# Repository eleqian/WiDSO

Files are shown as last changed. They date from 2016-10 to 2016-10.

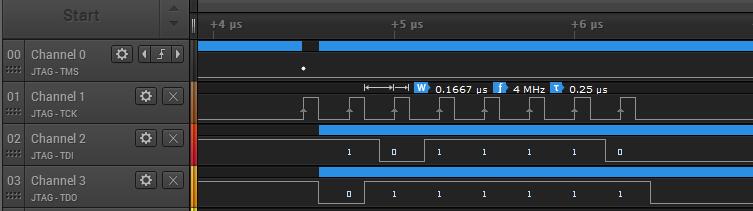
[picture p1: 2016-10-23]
Image/jtag_shift.jpg

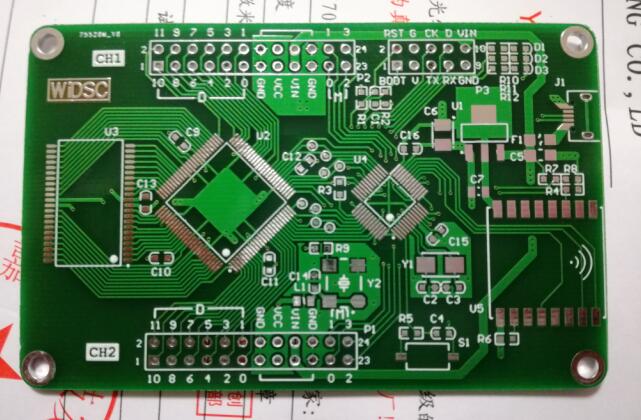
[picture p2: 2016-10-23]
Image/WiDSC_PCB.jpg

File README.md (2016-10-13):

# WiDSO
## 简介
通过Wi-Fi/USB显示和控制的数字示波器（DSO）/逻辑分析仪（LA）/信号发生器（DDS）等。  
由核心板（WiDSC）和扩展板两部分组成，最多可同时搭载两块扩展板。

### 核心板
- 通信接口：Wi-Fi b/g/n，USB FS，UART
- 扩展接口：两路，每路提供12个高速IO和4个ADC/PWM/SPI复用IO
- 存储空间：512k字节@16bits位宽
- 数据速率：采样/输出带宽之和最大100M字节/秒
- 调试方式：内建USB-Blaster和CDC串口，支持U盘方式升级
- 硬件组成：EPM240T100+IS61LV25616+STM32F103C8+ESP8266

### DSO扩展板（计划中）
- 通道数：1CH(8位)
- 采样率：100Mps Max
- 模拟带宽：>20MHz
- 输入幅度：+-4V(x1)/+-40V(x10) Max
- 触发方式：上升沿/下降沿，手动/单次/自动，支持触发信号输入/输出
- 硬件组成：ADC80100/AD9283-100，其余待定

### LA扩展板（计划中）
- 通道数：8CH
- 采样率：100Mps Max
- 输入电平：1.2~5.5V
- 逻辑触发：上升沿/下降沿/电平（任意通道组合），支持和DSO联合触发

### DDS扩展板（计划中）
- 通道数：1CH(8位)
- 采样率：100Mps Max
- 模拟带宽：>20MHz
- 输出幅度：+-4V Max，可调

### TFT扩展板（计划中）
- 分辨率：240*320
- 额外功能：Nor Flash/按键

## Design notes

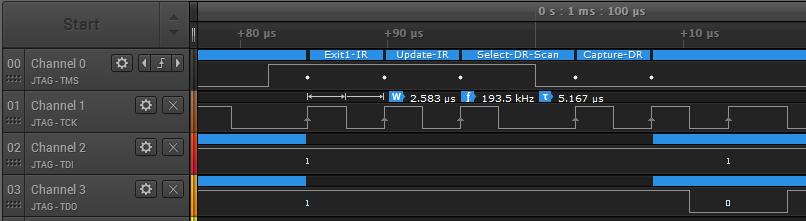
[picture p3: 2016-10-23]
Image/jtag_bitbang.jpg

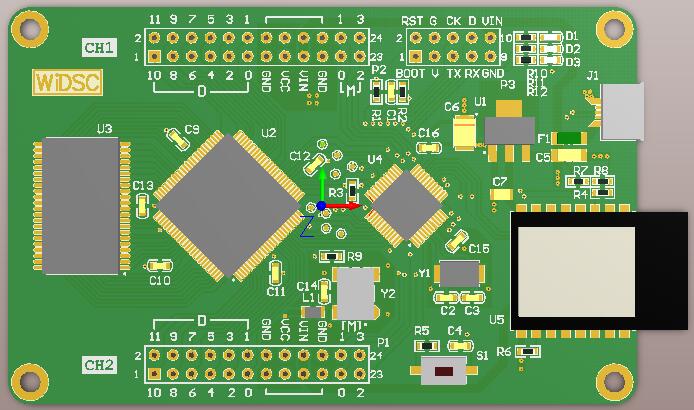
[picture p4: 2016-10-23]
Image/WiDSC_3D.jpg

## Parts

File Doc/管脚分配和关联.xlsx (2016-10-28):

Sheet: SRAM
Pin Designator | Name | Electrical Type
1 | A0 | Input
2 | A1 | Input
3 | A2 | Input
4 | A3 | Input
5 | A4 | Input
6 | C\E\ | Input
7 | IO0 | I/O
8 | IO1 | I/O
9 | IO2 | I/O
10 | IO3 | I/O
11 | VDD | Power
12 | GND | Power
13 | IO4 | I/O
14 | IO5 | I/O
15 | IO6 | I/O
16 | IO7 | I/O
17 | W\E\ | Input
18 | A5 | Input
19 | A6 | Input
20 | A7 | Input
21 | A8 | Input
22 | A9 | Input
23 | A10 | Input
24 | A11 | Input
25 | A12 | Input
26 | A13 | Input
27 | A14 | Input
28 | NC | Passive
29 | IO8 | I/O
30 | IO9 | I/O
31 | IO10 | I/O
32 | IO11 | I/O
33 | VDD | Power
34 | GND | Power
35 | IO12 | I/O
36 | IO13 | I/O
37 | IO14 | I/O
38 | IO15 | I/O
39 | L\B\ | Input
40 | U\B\ | Input
41 | O\E\ | Input
42 | A15 | Input
43 | A16 | Input
44 | A17 | Input

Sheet: MCU
 | ADC | TIM1 | TIM2 | TIM3 | TIM4 | SPI1 | SPI2 | USART1 | USART2 | USART3 | I2C | USB | OTHER
PA0 | * |  | * |  |  |  |  |  | * |  |  |  |  | 扩展接口
PA1 | * |  | * |  |  |  |  |  | * |  |  |  |  | CPLD
PA2 | * |  | * |  |  |  |  |  | * |  |  |  |  | 通信调试
PA3 | * |  | * |  |  |  |  |  | * |  |  |  |  | 其它
PA4 | * |  |  |  |  | *
PA5 | * |  |  |  |  | *
PA6 | * |  |  | * |  | *
PA7 | * | * |  | * |  | *
PA8 |  | *
PA9 |  | * |  |  |  |  |  | *
PA10 |  | * |  |  |  |  |  | *
PA11 |  | * |  |  |  |  |  | * |  |  |  | *
PA12 |  |  |  |  |  |  |  | * |  |  |  | *
PA13 |  |  |  |  |  |  |  |  |  |  |  |  | *
PA14 |  |  |  |  |  |  |  |  |  |  |  |  | *
PA15 |  |  | *
PB0 | * | * |  | *
PB1 | * | * |  | *
PB2 |  |  |  |  |  |  |  |  |  |  |  |  | *
PB3 |  |  | * |  |  | *
PB4 |  |  |  | * |  | *
PB5 |  |  |  | * |  | *
PB6 |  |  |  |  | * |  |  | * |  |  | *
PB7 |  |  |  |  | * |  |  | * |  |  | *
PB8 |  |  |  |  | *
PB9 |  |  |  |  | *
PB10 |  |  | * |  |  |  |  |  |  | * | *
PB11 |  |  | * |  |  |  |  |  |  | * | *
PB12 |  |  |  |  |  |  | * |  |  | *
PB13 | * |  |  |  |  |  | * |  |  | *
PB14 | * |  |  |  |  |  | *
PB15 | * |  |  |  |  |  | *
PC13 |  |  |  |  |  |  |  |  |  |  |  |  | *
PC14 |  |  |  |  |  |  |  |  |  |  |  |  | *
PC15 |  |  |  |  |  |  |  |  |  |  |  |  | *

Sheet: MCU<>CPLD
MCU | CPLD | 通用功能 | DSO_LA | DSO_2CH
PB12 | 34 | nCS
PB13 | 33 | SCK
PB14 | 30 | MISO
PB15 | 29 | MOSI
PB7 | 21 | MISC0
PB8 | 20 | MISC1
PB9 | 19 | MISC2
PC14 | 26 | IRQ0
PC15 | 27 | IRQ1

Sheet: ExtCH
Channel | Signal | DSO_LA | DSO_2CH
CH1 | D0
 | D1
 | D2
 | D3
 | D4
 | D5
 | D6
 | D7
 | D8
 | D9
 | D10
 | D11
 | M0
 | M1
 | M2
 | M3
CH2 | D0
 | D1
 | D2
 | D3
 | D4
 | D5
 | D6
 | D7
 | D8
 | D9
 | D10
 | D11
 | M0
 | M1
 | M2
 | M3

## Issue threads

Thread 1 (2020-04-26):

请问AS模式下，NCS_GETOUT()宏定义如何定义？

banalsheep, 2020-04-26:
如题，谢谢

RuidongWu, 2022-10-01:
我根据源码分析了下，NCS_GETOUT()的定义应该是获取NCS_OUT(d)的输出状态。
如果
#define NCS_OUT(d)      PAO(2) = (d)
那么
#define NCS_GETOUT()        PAI(2)

并且在uint8_t bport_shift_io(uint8_t d)函数里面定义：
if (NCS_GETOUT()==0) {
      BPORT_SHIFT_BIT();
      BPORT_SHIFT_BIT();
      BPORT_SHIFT_BIT();
      BPORT_SHIFT_BIT();
      BPORT_SHIFT_BIT();
      BPORT_SHIFT_BIT();
      BPORT_SHIFT_BIT();
      BPORT_SHIFT_BIT();
      return dshift & 0xff;
  }
就可以了。

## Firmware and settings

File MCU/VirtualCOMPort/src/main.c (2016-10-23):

/*
main.c

MIT License

Copyright (c) 2016 Yongqian Tang

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
THE SOFTWARE IS PROVIDED "AS IS", WITHOUT WARRANTY OF ANY KIND, EXPRESS OR
IMPLIED, INCLUDING BUT NOT LIMITED TO THE WARRANTIES OF MERCHANTABILITY,
FITNESS FOR A PARTICULAR PURPOSE AND NONINFRINGEMENT. IN NO EVENT SHALL THE
AUTHORS OR COPYRIGHT HOLDERS BE LIABLE FOR ANY CLAIM, DAMAGES OR OTHER
LIABILITY, WHETHER IN AN ACTION OF CONTRACT, TORT OR OTHERWISE, ARISING FROM,
OUT OF OR IN CONNECTION WITH THE SOFTWARE OR THE USE OR OTHER DEALINGS IN THE
SOFTWARE.
*/

#include <stdio.h>
#include "base.h"
#include "timebase.h"
#include "led.h"
#include "bitband.h"
#include "hw_config.h"
#include "usb_lib.h"
#include "usb_pwr.h"
#include "vcp.h"

/*-----------------------------------*/

// 判断按键是否按下
BOOL key_is_pressed(void)
{
    GPIO_InitTypeDef GPIO_InitStructure;
    BOOL is_press = FALSE;

    // 打开按键端口时钟
    RCC_APB2PeriphClockCmd(RCC_APB2Periph_GPIOC, ENABLE);

    GPIO_DeInit(GPIOC);
    
    // 初始化KEY端口(PC13)
    GPIO_InitStructure.GPIO_Pin = GPIO_Pin_13;
    GPIO_InitStructure.GPIO_Mode = GPIO_Mode_IPU;
    GPIO_Init(GPIOC, &GPIO_InitStructure);
    
    delay_ms(10);

    // KEY按下时为低电平
    is_press = !GPIO_ReadInputDataBit(GPIOC, GPIO_Pin_13);

    // 复位按键端口状态
    GPIO_DeInit(GPIOC);
    RCC_APB2PeriphClockCmd(RCC_APB2Periph_GPIOC, DISABLE);

    return is_press;
}

/*-----------------------------------*/

int main(void)
{
    RCC_APB2PeriphClockCmd(RCC_APB2Periph_AFIO, ENABLE);

    // disable JTAG，use SWD only
    GPIO_PinRemapConfig(GPIO_Remap_SWJ_JTAGDisable, ENABLE);

    timebase_init();
    led_init();
    vcp_init();
    
    // for debug use
    if (!key_is_pressed()) {
        USB_HW_Config();
        USB_Init();
    }

    led_flash(1000, 100, 0);

    while (1) {
        led_update();
        if (bDeviceState == CONFIGURED)
        {
            if (key_is_pressed()) {
                GPIO_ResetBits(GPIOB, GPIO_Pin_2);
                GPIO_ResetBits(GPIOB, GPIO_Pin_1);
                while (key_is_pressed());
                GPIO_SetBits(GPIOB, GPIO_Pin_2);
            }
        }
    }
}

/*-----------------------------------*/

#ifdef USE_FULL_ASSERT
void assert_failed(uint8_t *file, uint32_t line)
{
    /* User can add his own implementation to report the file name and line number,
       ex: printf("Wrong parameters value: file %s on line %d\r\n", file, line) */
    /* Infinite loop */
    while (1) {
    }
}
#endif //USE_FULL_ASSERT

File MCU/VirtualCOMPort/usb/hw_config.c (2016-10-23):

/**
  ******************************************************************************
  * @file    hw_config.c
  * @author  MCD Application Team
  * @version V4.0.0
  * @date    21-January-2013
  * @brief   Hardware Configuration & Setup
  ******************************************************************************
  * @attention
  *
  * <h2><center>&copy; COPYRIGHT 2013 STMicroelectronics</center></h2>
  *
  * Licensed under MCD-ST Liberty SW License Agreement V2, (the "License");
  * You may not use this file except in compliance with the License.
  * You may obtain a copy of the License at:
  *
  *        http://www.st.com/software_license_agreement_liberty_v2
  *
  * Unless required by applicable law or agreed to in writing, software
  * distributed under the License is distributed on an "AS IS" BASIS,
  * WITHOUT WARRANTIES OR CONDITIONS OF ANY KIND, either express or implied.
  * See the License for the specific language governing permissions and
  * limitations under the License.
  *
  ******************************************************************************
  */


/* Includes ------------------------------------------------------------------*/
#include "hw_config.h"
#include "usb_lib.h"
#include "usb_desc.h"
#include "usb_pwr.h"
#include "usb_prop.h"

/* Private typedef -----------------------------------------------------------*/
/* Private define ------------------------------------------------------------*/
/* Private macro -------------------------------------------------------------*/
#define ID1_ADDR        (0x1FFFF7E8)
#define ID2_ADDR        (0x1FFFF7EC)
#define ID3_ADDR        (0x1FFFF7F0)

/* Private variables ---------------------------------------------------------*/
/* Extern variables ----------------------------------------------------------*/
/* Private function prototypes -----------------------------------------------*/
void USB_Clock_Config(void);
void USB_Interrupts_Config(void);
void USB_GPIO_Config(void);
void USB_EXTI_Config(void);

/* Private functions ---------------------------------------------------------*/

/*******************************************************************************
* Function Name  : USB_HW_Config
* Description    : Configures Main system clocks & power.
* Input          : None.
* Return         : None.
*******************************************************************************/
void USB_HW_Config(void)
{
    /*!< At this stage the microcontroller clock setting is already configured,
    this is done through SystemInit() function which is called from startup
    file (startup_stm32xxx.s) before to branch to application main.
    To reconfigure the default setting of SystemInit() function, refer to
    system_stm32xxx.c file
    */

    USB_GPIO_Config();
    USB_Interrupts_Config();
    USB_EXTI_Config();
    USB_Clock_Config();
}

/*******************************************************************************
* Function Name  : USB_Clock_Config
* Description    : Configures USB Clock input (48MHz).
* Input          : None.
* Output         : None.
* Return         : None.
*******************************************************************************/
void USB_Clock_Config(void)
{
    /* Select USBCLK source */
    RCC_USBCLKConfig(RCC_USBCLKSource_PLLCLK_1Div5);

    /* Enable the USB clock */
    RCC_APB1PeriphClockCmd(RCC_APB1Periph_USB, ENABLE);
}

/*******************************************************************************
* Function Name  : USB_Interrupts_Config.
* Description    : Configures the USB interrupts.
* Input          : None.
* Output         : None.
* Return         : None.
*******************************************************************************/
void USB_Interrupts_Config(void)
{
    NVIC_InitTypeDef NVIC_InitStructure;

    /* 2 bit for pre-emption priority, 2 bits for subpriority */
    NVIC_PriorityGroupConfig(NVIC_PriorityGroup_2);

    /* Enable the USB interrupt */
    NVIC_InitStructure.NVIC_IRQChannel = USB_LP_CAN1_RX0_IRQn;
    NVIC_InitStructure.NVIC_IRQChannelPreemptionPriority = 2;
    NVIC_InitStructure.NVIC_IRQChannelSubPriority = 0;
    NVIC_InitStructure.NVIC_IRQChannelCmd = ENABLE;
    NVIC_Init(&NVIC_InitStructure);

    /* Enable the USB Wake-up interrupt */
    NVIC_InitStructure.NVIC_IRQChannel = USBWakeUp_IRQn;
    NVIC_InitStructure.NVIC_IRQChannelPreemptionPriority = 1;
    //NVIC_InitStructure.NVIC_IRQChannelCmd = ENABLE;
    NVIC_Init(&NVIC_InitStructure);
}

/*******************************************************************************
* Function Name  : USB_Cable_Ctrl.
* Description    : Software Connection/Disconnection of USB Cable.
* Input          : NewState: new state.
* Output         : None.
* Return         : None
*******************************************************************************/
void USB_Cable_Ctrl(FunctionalState NewState)
{
    if (NewState != DISABLE) {
        GPIO_SetBits(GPIOA, GPIO_Pin_15);
    } else {
        GPIO_ResetBits(GPIOA, GPIO_Pin_15);
    }
}

/*******************************************************************************
* Function Name  : USB_GPIO_Config
* Description    : Configures the different GPIO ports.
* Input          : None
* Output         : None
* Return         : None
*******************************************************************************/
void USB_GPIO_Config(void)
{
    GPIO_InitTypeDef GPIO_InitStructure;

    /* Enable the USB disconnect GPIO clock */
    RCC_APB2PeriphClockCmd(RCC_APB2Periph_GPIOA, ENABLE);

    /* PA15 used as USB pull-up */
    GPIO_InitStructure.GPIO_Pin = GPIO_Pin_15;
    GPIO_InitStructure.GPIO_Mode = GPIO_Mode_Out_PP;
    GPIO_InitStructure.GPIO_Speed = GPIO_Speed_2MHz;
    GPIO_Init(GPIOA, &GPIO_InitStructure);
}

/*******************************************************************************
* Function Name : USB_EXTI_Config.
* Description   : Configure the EXTI lines for Key and Tamper push buttons.
* Input         : None.
* Output        : None.
* Return value  : The direction value.
*******************************************************************************/
void USB_EXTI_Config(void)
{
    EXTI_InitTypeDef EXTI_InitStructure;

    /* Configure the EXTI line 18 connected internally to the USB IP */
    EXTI_ClearITPendingBit(EXTI_Line18);
    EXTI_InitStructure.EXTI_Line = EXTI_Line18;
    EXTI_InitStructure.EXTI_Trigger = EXTI_Trigger_Rising;
    EXTI_InitStructure.EXTI_LineCmd = ENABLE;
    EXTI_Init(&EXTI_InitStructure);
}

/*******************************************************************************
* Function Name  : Enter_LowPowerMode.
* Description    : Power-off system clocks and power while entering suspend mode.
* Input          : None.
* Output         : None.
* Return         : None.
*******************************************************************************/
void Enter_LowPowerMode(void)
{
    /* Set the device state to suspend */
    bDeviceState = SUSPENDED;
}
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

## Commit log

2016-07-22 初始版本，包括开发中的硬件和CPLD源码
    [DSPComm.SchDoc, ExtConn.SchDoc, PowerMisc.SchDoc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]
2016-07-31 修改PCB尺寸，完成布局布线
    [DSPComm.SchDoc, ExtConn.SchDoc, PowerMisc.SchDoc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]
2016-08-27 添加时序设计和PCB细节调整
    [SampleCtrl.SchDoc, WiDSO.PcbDoc]
2016-09-17 1.修改USB接口为直插焊接封装； 2.修改外扩接口电源排列； 3.布线细节调整。
    [DSPComm.SchDoc, ExtConn.SchDoc, PowerMisc.SchDoc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]
2016-09-22 1.修改扩展接口信号次序； 2.CPLD增加一个LED指示输出； 3.修改USB/自恢复保险等器件封装； 4.局部布线和丝印调整。
    [DSPComm.SchDoc, ExtConn.SchDoc, PowerMisc.SchDoc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]
2016-09-30 PCB：添加测试点 CPLD：增加通用顶层，方便管脚映射
    [DSPComm.SchDoc, PowerMisc.SchDoc, SampleCtrl.SchDoc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]
2016-10-06 顶层中文目录更名为英文
    [DSPComm.SchDoc, ExtConn.SchDoc, PowerMisc.SchDoc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]
2016-10-10 新增实现BootLoader和USB-Blaster
2016-10-23 VCP基础版本，基于官方示例修改
2016-10-23 添加图片
2016-10-23 更新工程到MDK5，修正IAP文件生成
2016-10-28 添加DSO功能的CPLD寄存器定义表，修改寄存器地址
    [CPLD寄存器定义.xlsx]
2016-10-28 调整CPLD和硬件工程路径
    [DSPComm.SchDoc, ExtConn.SchDoc, PowerMisc.SchDoc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]
2016-10-28 合并管脚定义文档
    [SRAM管脚.xlsx, STM32管脚功能分配.xlsx, 管脚分配和关联.xlsx]
2016-10-28 添加时序设计文档打开方式说明

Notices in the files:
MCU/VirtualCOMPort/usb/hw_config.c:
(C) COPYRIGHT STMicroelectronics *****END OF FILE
